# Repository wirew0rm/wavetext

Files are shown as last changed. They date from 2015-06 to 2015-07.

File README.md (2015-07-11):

# wavetext
A very affordable POV Display for an etching and soldering workshop.

* Costs ~5€
* 10x5 Font, 62 Characters
* 10 Texts with 12 Characters each programmable
* Programmable from webpage by using a flickering image
* Detection of waving speed and direction

## Needed packages

 - avr-gcc
 - avr-libc
 - avrdude

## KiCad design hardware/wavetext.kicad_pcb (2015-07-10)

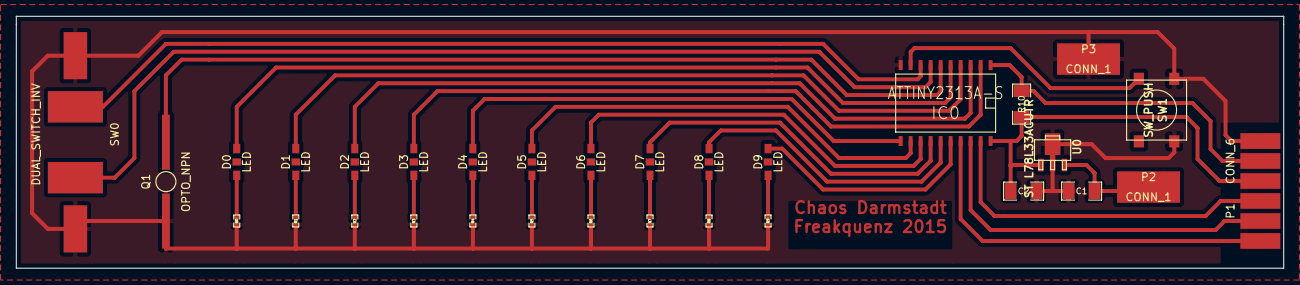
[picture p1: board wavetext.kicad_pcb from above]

Board: 2 copper layers, 161.0 x 32.0 mm, 31 parts (0 on the bottom side), 31 nets.

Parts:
C1, C2: C; SM1206
D0, D1, D2, D3, D4, D5, D6, D7, D8, D9: LED
IC0: ATTINY2313A-S; SO20L
P1: CONN_6; PCBISP
P2, P3: CONN_1; Powerpad
Q1: OPTO_NPN; Fototransistor
R0, R1, R2, R3, R4, R5, R6, R7, R8, R9: 40; SM0402
R10: 1k; SM1206
SW0: DUAL_SWITCH_INV; Wackelschalter
SW1: SW_PUSH; SW_PUSH_SMD
U0: ST L78L33ACUTR; sot89

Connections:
GND: C1.2, C2.2, IC0.10, P1.6, P3.1, Q1.1, R0.2, R1.2, R2.2, R3.2, R4.2, R5.2, R6.2, R7.2, R8.2, R9.2, SW0.2, SW1.1, U0.2
unnamed: D2.1, IC0.3
unnamed: D8.1, IC0.15
unnamed: D7.1, IC0.14
unnamed: D6.1, IC0.13
unnamed: D5.1, IC0.12
unnamed: D4.1, IC0.11
unnamed: D3.1, IC0.2
unnamed: D1.1, IC0.4
unnamed: D0.1, IC0.5
unnamed: IC0.6, Q1.3
unnamed: IC0.9, SW1.2
unnamed: D9.1, IC0.16
unnamed: IC0.18, P1.2
unnamed: IC0.19, P1.3
unnamed: IC0.7, SW0.1
unnamed: IC0.8, SW0.3
unnamed: C2.1, IC0.20, P1.4, R10.1, U0.1
unnamed: IC0.1, P1.5, R10.2
unnamed: IC0.17, P1.1
unnamed: D7.2, R7.1
unnamed: D6.2, R6.1
unnamed: D5.2, R5.1
unnamed: D3.2, R3.1
unnamed: D2.2, R2.1
unnamed: D1.2, R1.1
unnamed: D0.2, R0.1
unnamed: D4.2, R4.1
unnamed: D9.2, R9.1
unnamed: D8.2, R8.1
VCC: C1.1, P2.1, U0.3

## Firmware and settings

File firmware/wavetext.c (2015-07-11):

/*
 wavetext - a very affordable POV Display

 - 10 LEDs
 - 1 ATtiny2313
 - some resistors
 - Clock: 8MHz (internal)
*/

#define F_CPU 8000000UL  // 8 MHz

#include <avr/io.h>
#include <avr/eeprom.h>
#include <avr/interrupt.h>
#include <util/delay.h>

#include "font.h"


const uint8_t eemem[] EEMEM = "Freakquenz{Chaos{DA{{{Socke{{{{{{Wirew0rm{{";

void setupInterrupts() {
    GIMSK |= 0b00010000;    // allow pcint2
    PCMSK2 = 0b00001000;    // only on this pin
    sei();                  // enable interrupts
}

void setLEDs(uint8_t bot, uint8_t top) {
    uint8_t a, b, d;
    a = top;
    b = bot & 0b00011111;
    d = (bot & 0b00100000) << 1;
    d |= (bot & 0b11000000) >> 6;

    PORTA = a;
    PORTB = b;
    PORTD = 0b00111000 | d;
}

//index of currently active character
volatile uint8_t chr = 0;
//xpos in currently active character (-1 = inactive)
volatile int8_t x = -1;
//duraction for one column in counter ticks
volatile uint8_t columnduration = 0xff;

ISR(TIMER0_COMPA_vect) {
    x++;
    if (x == FONT_CHAR_WIDTH) {
        x = 0;
        chr++;
        if (chr == 11) {
			      //Disable timer Interrupts
            TIMSK &= ~(1 << OCIE0A);
						// Disable LEDs
            x = -1;
        }
    }
}

ISR(TIMER1_COMPA_vect) {
	// set controller to sleep
	TCCR1B = 0;
}

ISR(PCINT2_vect) {
    if (PCMSK2 == 0b00001000 && (PIND & 0b00001000) == 0) {
        // forward
        // reset cursors
        chr = 0;
        x = -14;
        // read counter
        TCCR1B = 0;                         // disable timer
        uint32_t timeout = TCNT1L;          // read counter
        timeout |= TCNT1H << 8;
				// a full cycle gets measured and in the beginning and the end a char is omitted
        //timeout /= (26 * FONT_CHAR_WIDTH);    // divide counter to get update intervall
        timeout >>= 8;    // divide counter to get update intervall
        columnduration = timeout & 0xff;
				// setup timer
        TCNT0  = 0;
        TCNT1H = 0;                         // clear timer
        TCNT1L = 0;
				// set delay time
        OCR0A = timeout;
				// start timer
        TIMSK |= (1 << OCIE1A);               // enable timer1 compare A interrupt
        TIMSK |= (1 << OCIE0A);               // enable timer0 compare A interrupt
        TCCR1B = (1 << CS12) | (1 << CS10);     // re-enable using prescaler 1024 (gives about 839 ms time to overflow and 128 us resolution)
        TCCR0B = (1 << CS12) | (1 << CS10);     // re-enable using prescaler 1024 (gives about 839 ms time to overflow and 128 us resolution)
        // next interrupt on other side
        PCMSK2 = 0b00010000;
    } else if (PCMSK2 == 0b00010000 && (PIND & 0b00010000) == 0) {
        // backward
        TIMSK &= ~(1 << OCIE1A);  // disable timer compare interrupt
				x = -1;                   // disable LEDs
        // next interrupt on other side
        PCMSK2 = 0b00001000;
    }
}

int main(void) {
		// Setup Direction of IO-Pins
    DDRA = 0b00000011; // 5pins not accessible,Reset,LED- 0-1
    DDRB = 0b00011111; // SCK,MISO,MOSI, 5xLED (1=Out, 0=In)
    DDRD = 0b01000011; // not acessible, led, sw1, 2*sensDir, 3x led

		// Blink all LEDs to indicate proper device operation
    setLEDs(0b11111111, 0b00000011);
    _delay_ms(70);
    setLEDs(0, 0);

		// setup timers
    OCR1AH = 0b01111111;                // set sleep delay
    OCR1AL = 0b11111111;
		TCCR1A = 0;                         // normal counter mode
		TCCR0A |= 2;                        // timer0 ctc mode

    // initialize
    chr = 0;
    x = 0;

		// setup the interrupt routines for the wave detection
    setupInterrupts();

		//main loop
    while (1) {
			if (x >= 0) {
        uint8_t c = eeprom_read_byte(&eemem[chr]) - 0x30;
        uint8_t bot = pgm_read_byte(&font_bottom[c * FONT_CHAR_WIDTH + x]);
        uint8_t top = pgm_read_byte(&font_top[(c * FONT_CHAR_WIDTH + x) >> 2]);
        top >>= (6 - (x << 1));
        setLEDs(bot, top);
			} else {
				setLEDs(0,0);
			}
    }
}

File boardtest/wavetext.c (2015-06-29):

/*

	 wavetext - a very affordable POV Display

	 10 LEDs
	 1 ATtiny2313
	 some resistors

	 Clock: 8MHz (internal)

*/

#include <avr/io.h>
//#include <stdio.h>
//#include <stdlib.h>

#define F_CPU 8000000UL  // 8 MHz

#include <util/delay.h>

int main (void) {
	int state = 0;
	int count = 0;

	DDRA  = 0b00000011; // 5pins not accessible,Reset,LED- 0-1
	PORTA = 0b00000000;

  DDRB  = 0b00011111; // SCK,MISO,MOSI,LED+ 0-4 (1=Out, 0=In)
  PORTB = 0b00000000;

	DDRD  = 0b00000000; // not acessible, nc, Button, nc, 2*sensDir, 2*receive
	PORTD = 0b00101100;

  while (1==1) {
    //waitms(100);
		if !(PIND & 1<<5) {
			PORTB = 0b00000000;
			PORTA |= 0b00000011;
		}else if ((state==0) && !(PIND & 1<<2)) {
			state = 1;
			count++;
			PORTB = ~(count >> 1) & 0b00011111;
			if (count & 1) {
				PORTA |= 1 << 1;
				PORTA &= ~(1 << 0);
			} else {
				PORTA |= 1 << 0;
				PORTA &= ~(1 << 1);
			}
		} else if ((state==1) && !(PIND & 1<<3)) {
			state = 0;
			count++;
			PORTB = ~(count >> 1) & 0b00011111;
			if (count & 1) {
				PORTA |= 1 << 1;
				PORTA &= ~(1 << 0);
			} else {
				PORTA |= 1 << 0;
				PORTA &= ~(1 << 1);
			}
		} else { 
			PORTB = ~(count >> 1) & 0b00011111;
			if (count & 1) {
				PORTA |= 1 << 1;
				PORTA &= ~(1 << 0);
			} else {
				PORTA |= 1 << 0;
				PORTA &= ~(1 << 1);
			}
		}
  }
}

//void waitms(int ms) {
//  int i;
//  for (i=0;i<ms;i++) _delay_ms(1);
//}

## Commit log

2015-06-29 Added board test
2015-06-29 kicad projekt angelegt
    [wavetext.kicad_pcb, wavetext.sch]
2015-06-29 Activate all leds on button press, not the other way round
2015-06-30 changed design to use 10 microcontroller pins instead of 7
    [wavetext.kicad_pcb, wavetext.sch]
2015-07-07 completed schema and pcb layout
    [wavetext.kicad_pcb, wavetext.sch]
2015-07-07 improved schematic and pcb
    [wavetext.kicad_pcb, wavetext.sch]
2015-07-08 Wackelschalter footprint added
2015-07-08 rearranged pcb parts
    [wavetext.kicad_pcb, wavetext.sch]
2015-07-08 Fixed pin numbering on wackelschalter.
    Completed wirering on pcb.
    [wavetext.kicad_pcb, wavetext.sch]
2015-07-08 changed led footprint
    [wavetext.kicad_pcb]
2015-07-09 PCB fertig
    [wavetext.kicad_pcb, wavetext.sch]
2015-07-09 Board als SVG
2015-07-10 first version using the timer. does not work!
    [wavetext.c]
2015-07-10 PCB final, breitere Leiterbahnen, spannungsregler richtigrum
    [wavetext.kicad_pcb, wavetext.sch]
2015-07-11 alternatives timergedöns
